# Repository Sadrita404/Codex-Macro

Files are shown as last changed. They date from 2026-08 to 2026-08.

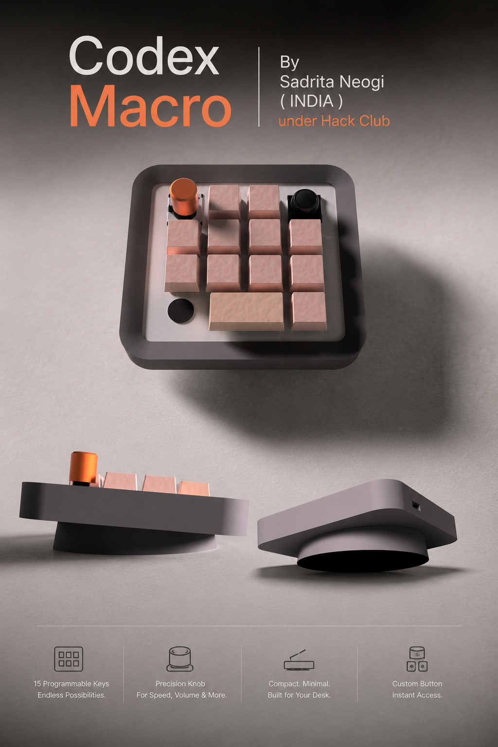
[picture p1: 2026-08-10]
Poster/2Poster.png

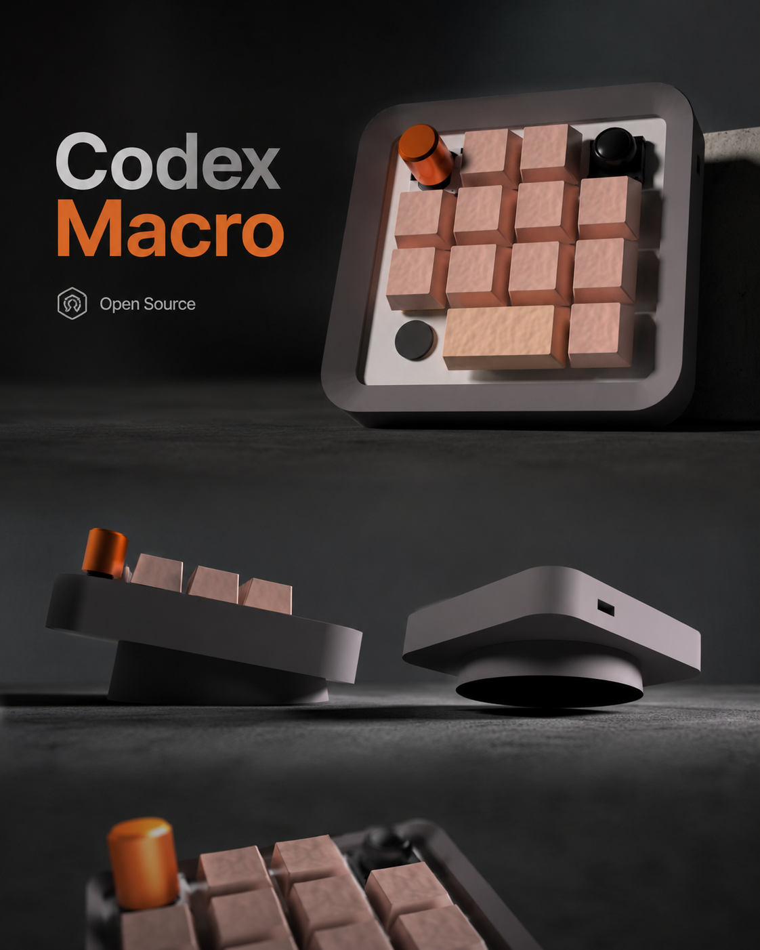
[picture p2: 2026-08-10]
Poster/1Poster.png

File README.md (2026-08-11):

<div align="center">
  <table border="0" cellpadding="0" cellspacing="0">
    <tr>
      <td align="center" style="background: #ffffff; border: 1px solid #d0d7de; border-radius: 12px; padding: 16px; box-shadow: 0 4px 12px rgba(0,0,0,0.05);">
        Rough Layout For The PCB
        <div style="margin-top: 12px; font-family: -apple-system, BlinkMacSystemFont, 'Segoe UI', Helvetica, Arial, sans-serif; font-size: 13px; color: #57606a; font-weight: 500;">
      </td>
    </tr>
  </table>
</div>

|Title | Codex Macro |
|:-- |:--|
|Author | Sadrita Neogi|

## Overview
This is a fully open source Codex Macro , which is basically the clone of Codex Micro which is made by Open AI.

## Why I chose this project?
Actually, behind choosing this project when I saw the post of open AI that they are introducing and codex micro for their codex app then it kind of strike me that I can also make something like that. This is basically an micro pad, but with special feature such as like audio input custom keys with Rotary encoder and joystick.
##  How to use this project

So for using this project, we can do it directly connected to our desktop or laptop. Then we can use it as an Micropath as well as it will also works with the codex app to toggle the different features of the app.

## Features 
* Programmable Mechanical Switches
* Rotary Encoders (Knobs)
* Multi-Directional Joysticks & Switches
* Integrated Microcontrolle (Waveshare RP2040-Zero)
* Microphones (for voice commands)

<div align="center">
  
## Schematic

Screenshot 2026-08-11 at 6 11 34 AM

<div align="center">
  <h2> PCB </h2>
<table width="100%">
  <tr>
    <td width="50%" align="center">
      
    </td>
    <td width="50%" align="center">
      
    </td>
  </tr>
</table>

  <table border="0" cellpadding="10" cellspacing="0" style="border-collapse: collapse;">
    <tr>
      <!-- FRONT SIDE CARD -->
      <td align="center" valign="top" width="50%" style="background: #ffffff; border: 1px solid #d0d7de; border-radius: 12px; padding: 16px; box-shadow: 0 4px 12px rgba(0,0,0,0.05);">
        Front Side View
        <div style="margin-top: 12px; font-family: -apple-system, BlinkMacSystemFont, 'Segoe UI', Helvetica, Arial, sans-serif; font-size: 13px; color: #57606a; font-weight: 600; text-transform: uppercase; letter-spacing: 0.5px;">
          ▲ Front Side View
        </div>
      </td>
      <!-- SPACER FOR GITHUB MOBILE DEGRADATION -->
      <td width="2%">&nbsp;</td>
      <!-- BACK SIDE CARD -->
      <td align="center" valign="top" width="50%" style="background: #ffffff; border: 1px solid #d0d7de; border-radius: 12px; padding: 16px; box-shadow: 0 4px 12px rgba(0,0,0,0.05);">
        Back Side View
        <div style="margin-top: 12px; font-family: -apple-system, BlinkMacSystemFont, 'Segoe UI', Helvetica, Arial, sans-serif; font-size: 13px; color: #57606a; font-weight: 600; text-transform: uppercase; letter-spacing: 0.5px;">
          ▲ Back Side View
        </div>
      </td>
    </tr>
  </table>
</div>
</div>

<h2> Fusion Renders</h2>
<table width="100%">
  <tr>
    <td width="50%" align="center">
      Render 1
    </td>
    <td width="50%" align="center">
      Render 2
    </td>
  </tr>
  <tr>
    <td width="50%" align="center">
      Render 4
    </td>
    <td width="50%" align="center">
      Render 6
    </td>
  </tr>
</table>

<div align="center">
  <h2> Bill of Materials</h2>
</div>

| Component Name | Purpose | Qty | Total Price | Source Link | Distributor |
| :--- | :--- | :---: | :---: | :---: | :---: |
| **PCB(moq5)** | The Main Board | 5 | $4.00 | [JLC PCB](https://jlcpcb.com/) | JLC PCB |
| **Waveshare RP2040-Zero** | The Controller Board | 1 | $4.50 | [Robu](https://robu.in/product/waveshare-rp2040-zero-without-header/) | Robu |
| **SMD LED** | For the board | 20 | $0.20 | [Robu](https://robu.in/product/xl-1608ubc-04-xinglight-20ma-240mcd-colorless-transparent-lens-20%e2%84%8385%e2%84%83-positive-stick-455nm475nm-blue-120-70mw-3-3v-0603-led-i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) | Robu |
| **Microphone Module** | For the audio input | 1 | $1.60 | [Robu](https://robu.in/product/inmp441-mems-high-precision-omnidirectional-microphone-module-i2s/) | Robu |
| **Joystick Switches** | For the Control | 1 | $0.35 | [Robu](https://robu.in/product/10109-6p-wx-shou-han-smd-6p10x10mm-multi-directional-switches-rohs/) | Robu |
| **47 Ohm 0.25W Metal Film Resistor** | For the led | 40 | $0.12 | [Robu](https://robu.in/product/47-ohm-0-25w-metal-film-resistor-pack-of-100/) | Robu |
| **Rotary Encoder** | For the Control | 1 | $0.40 | [Robu](https://robu.in/product/hongyan-rs11-threadless-insert/) | Robu |
| **1N4148 1W Zener Diode** | For the keys | 20 | $0.30 | [Robu](https://robu.in/product/1n4148-1w-zener-diode-pack-of-50/) | Robu |
| **Keycaps(set)** | For the keys | 1 | $7.50 | [Neomacro](https://neomacro.in/products/mahjong-mx-style-keycaps?variant=50665429369110) | Neomacro |
| **Low Profile Switches** | For the Board | 1 | $13.00 | [Neomacro](https://neomacro.in/products/kailh-choc-v2-low-profile-switches?variant=51316563312918) | Neomacro |
| **PLA Filament** | For 3d Print ( I have 3d Printer) | 1 | $6.00 | [Numakers](https://india.numakers.com/products/pla?variant=45708299305129) | Numakers |
| **Shipping** | incl. PCB | - | $16.00 | - | - |
| **Tax** | - | - | $2.20 | - | - |
| **Total (Rounded Off)** | - | - | **$60.00** | - | - |

</div>

## Copyright and License
Copyright (c) 2026 Sadrita Neogi. All rights reserved.

All files are licensed under the MIT license. For more information, see the [LICENSE](LICENSE).

Project Under Hack Club

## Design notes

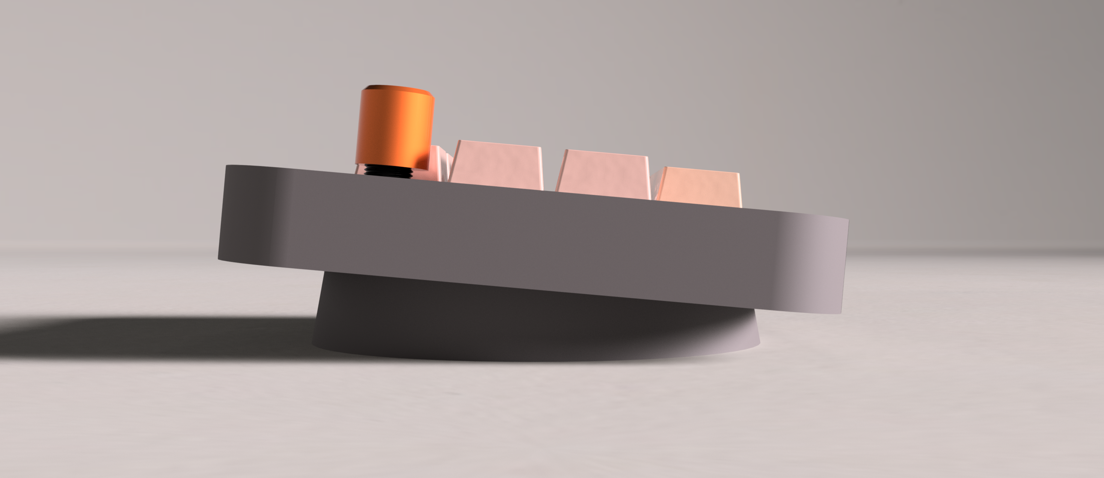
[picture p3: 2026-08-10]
Renders/Render 2.png

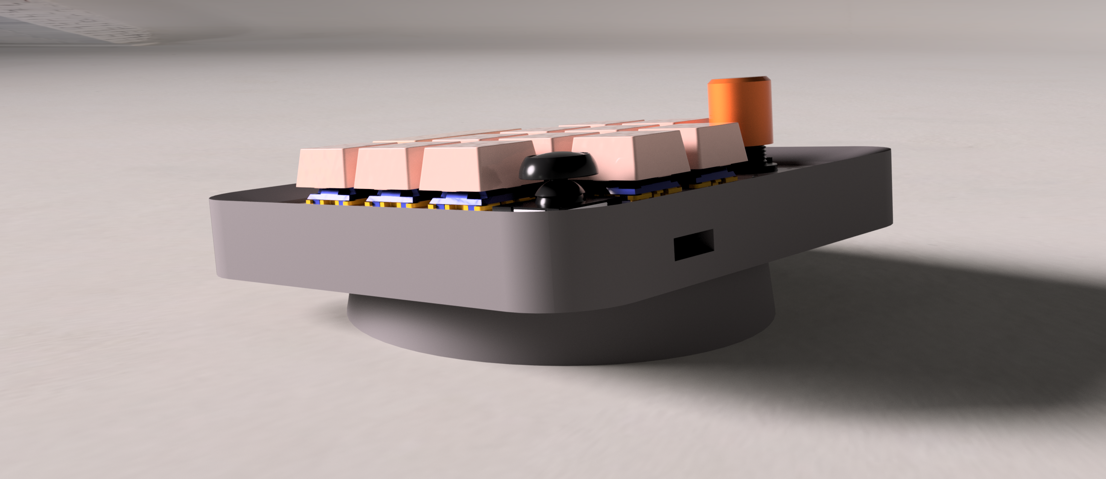
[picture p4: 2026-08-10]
Renders/Render 5.png

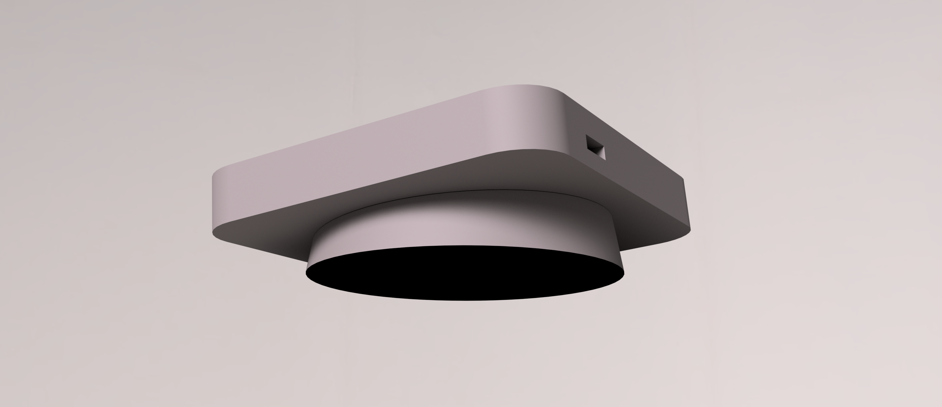
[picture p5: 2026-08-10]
Renders/Render 4.png

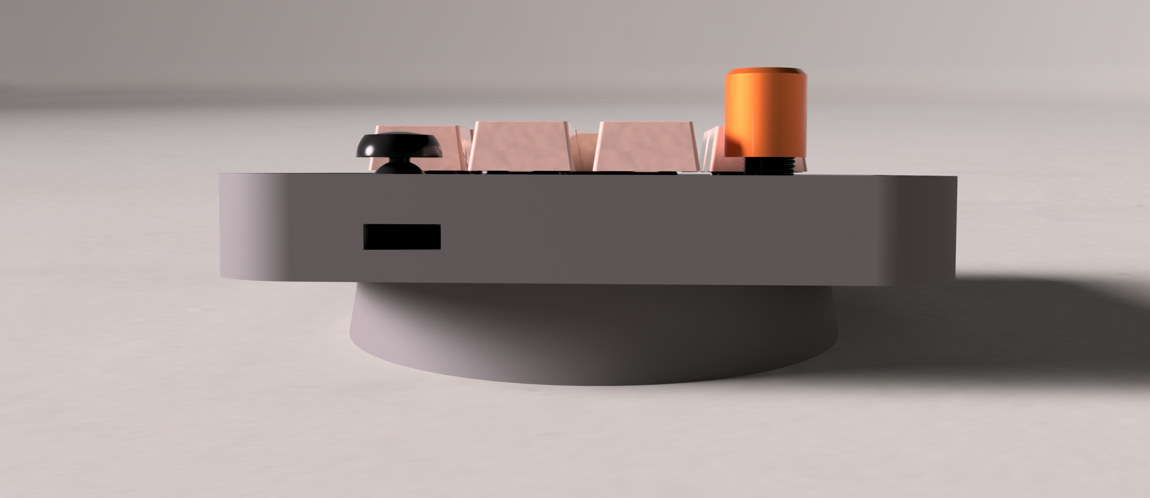
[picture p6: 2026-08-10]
Renders/Render 6.png

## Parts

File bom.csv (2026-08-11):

Name | Purpose | Quantity | Price in USD | Link | Distributor
PCB(moq5) | The Main Board | 5 | 4 | https://jlcpcb.com/ | JLC PCB
Waveshare RP2040-Zero | The Controller Board | 1 | 4.5 | https://robu.in/product/waveshare-rp2040-zero-without-header/ | Robu
SMD LED | For the board | 20 | 0.2 | https://robu.in/product/xl-1608ubc-04-xinglight-20ma-240mcd-colorless-transparent-lens-20%e2%84%8385%e2%84%83-positive-stick-455nm475nm-blue-120-70mw-3-3v-060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 | Robu
Microphone Module | For the audio input | 1 | 1.6 | https://robu.in/product/inmp441-mems-high-precision-omnidirectional-microphone-module-i2s/ | Robu
Joystick Switches | For the Control | 1 | 0.35 | https://robu.in/product/10109-6p-wx-shou-han-smd-6p10x10mm-multi-directional-switches-rohs/ | Robu
47 Ohm 0.25W Metal Film Resistor | For the led | 40 | 0.12 | https://robu.in/product/47-ohm-0-25w-metal-film-resistor-pack-of-100/ | Robu
Rotary Encoder | For the Control | 1 | 0.4 | https://robu.in/product/hongyan-rs11-threadless-insert/ | Robu
1N4148 1W Zener Diode | For the keys | 20 | 0.3 | https://robu.in/product/1n4148-1w-zener-diode-pack-of-50/ | Robu
Keycaps(set) | For the keys | 1 | 7.5 | https://neomacro.in/products/mahjong-mx-style-keycaps?variant=50665429369110 | Neomacro
Low Profile Switches | For the Board | 1 | 13 | https://neomacro.in/products/kailh-choc-v2-low-profile-switches?variant=51316563312918 | Neomacro
PLA Filament | For 3d Print ( I have 3d Printer) | 1 | 6 | https://india.numakers.com/products/pla?variant=45708299305129 | Numakers
Shipping | incl. PCB |  | 16
Tax |  |  | 2.2
Total round off |  |  | 60

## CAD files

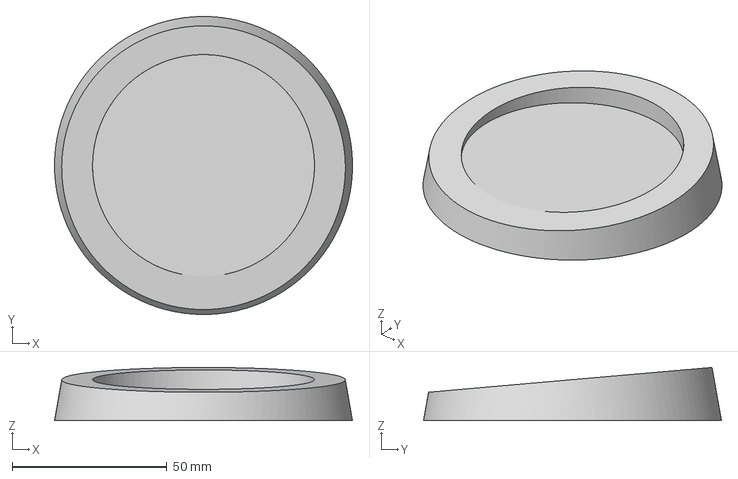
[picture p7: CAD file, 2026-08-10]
3d Print/Bottom Lid.3mf
96.2 x 96.2 x 17.1 mm

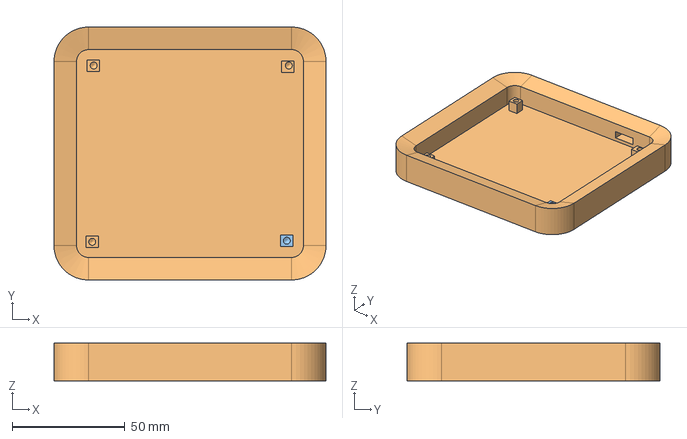
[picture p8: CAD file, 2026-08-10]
CAD/Codex Macro Case.step
120.5 x 112.0 x 16.7 mm

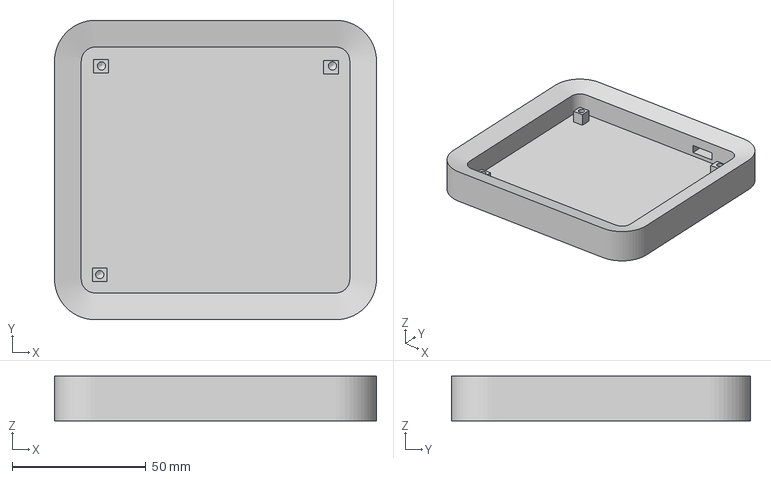
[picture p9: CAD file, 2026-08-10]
3d Print/Base Case.3mf
120.5 x 112.0 x 16.7 mm

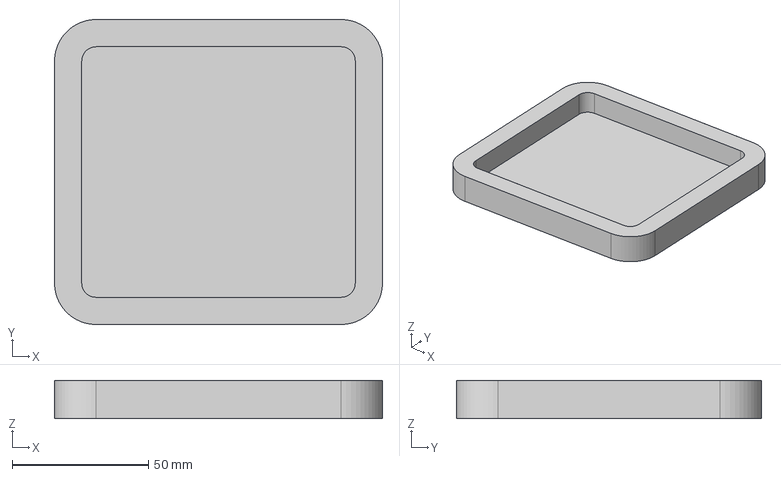
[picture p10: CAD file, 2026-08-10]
CAD/Codex Macro lid.step
120.5 x 112.0 x 14.0 mm

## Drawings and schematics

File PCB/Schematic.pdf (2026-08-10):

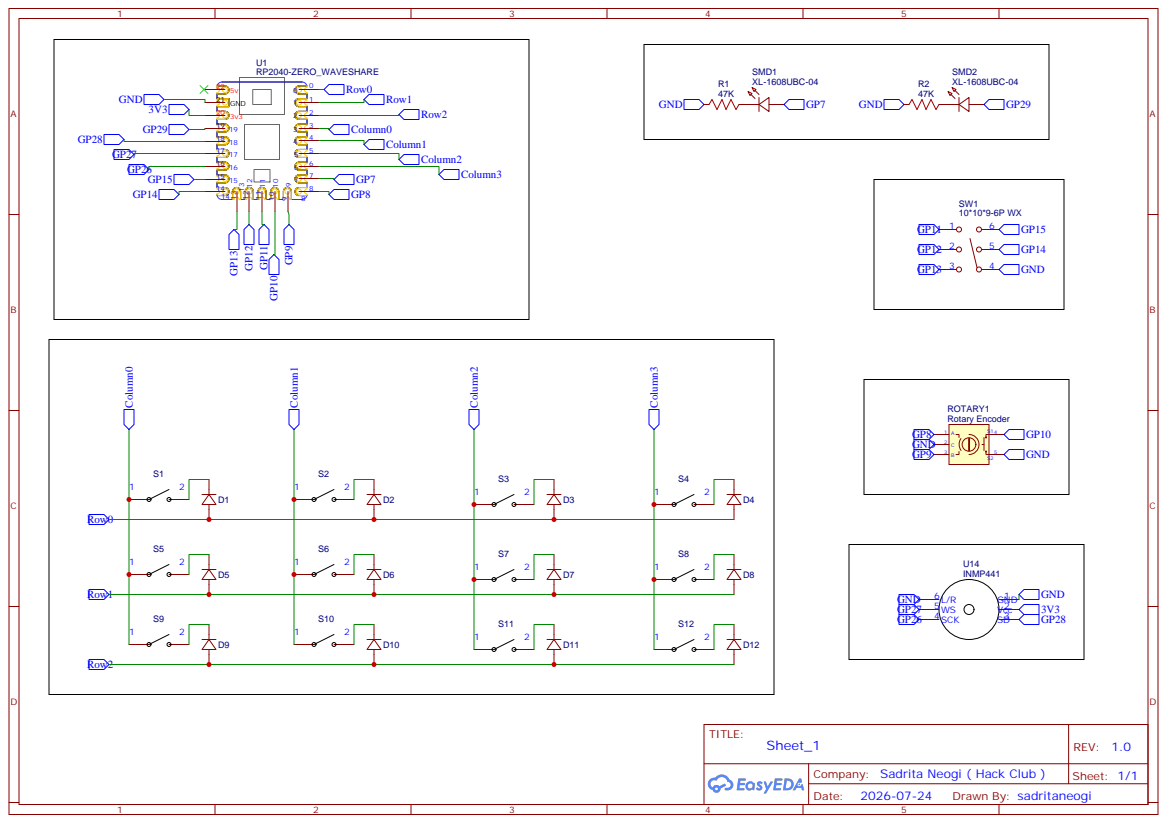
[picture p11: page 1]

Company: Sadrita Neogi ( Hack Club )

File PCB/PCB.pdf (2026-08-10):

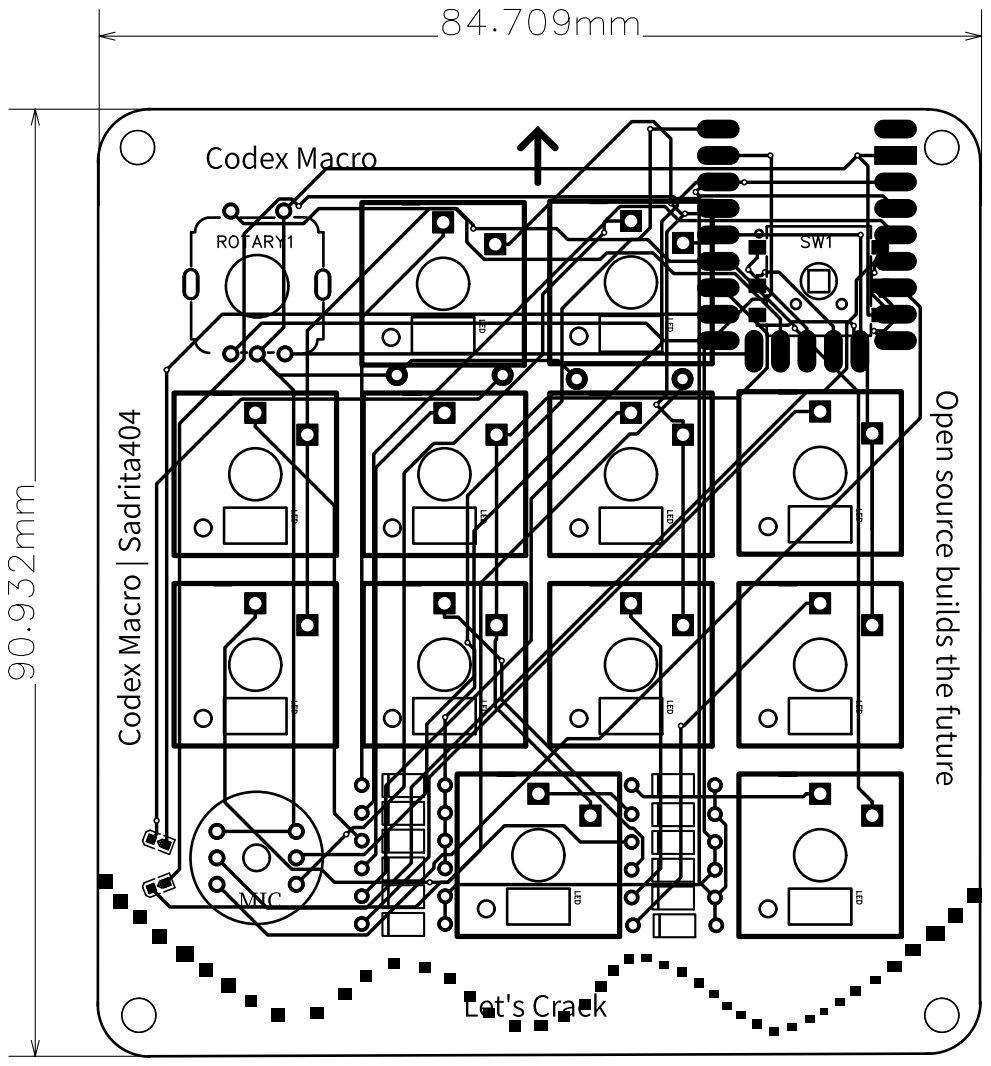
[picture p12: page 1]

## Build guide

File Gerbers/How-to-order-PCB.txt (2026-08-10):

How to Order PCB

Please refer to:
https://docs.easyeda.com/en/PCB/Order-PCB

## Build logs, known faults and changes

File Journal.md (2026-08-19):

| Title | Codex Macro|
| :-- | :---|
|Author |Sadrita Neogi|
|Type | Hardware  |
Total Hrs |  19.2 |

## Started design designing the product and taking info from the previous one that had already existed.

So for this project the main design inspo for me was the all new Codex Micro by Open Ai ( made by the company Work Louderand I like the brand ) So I thought to make a same thing under budget as the Codex Micro is costed at $230which is too much for what it's offer so I named it " Codex Macro "

#### Inspo 



#### Mine Design 

design

This is just the wire frame of the project and I have made it just for the reference so that I can use it to design the PCb also the CAD model of that

_Total Time = 15 min_

---

## Now I started research about the components that I can use for this project that can be cost-effective as well as easy to use, and I can get all the data sheet of that so that I can make the PCB

For the main Control Board I choose the **Waveshare RP2040-Zero** as this is not too much expensive and I can use it to control most of the components and this will done the job done.
Now I need to see the data sheet of this Waveshare RP2040-Zero to make sure that it will work with all the components.

#### And I am using this datasheet for this which is uploaded in the roubbu.in website - [Link DOC](https://robu-prod-media.s3.ap-south-1.amazonaws.com/products/attachments/8VoZujeD3ppn3I6F0tEKGp6TgBw9RXaVQka7HNXm.pdf)

Screenshot 2026-08-11 at 3 00 20 AM
Screenshot 2026-08-11 at 3 00 34 AM

### The AHB-Lite Crossbar are perfect for the work that I will do with it 

Screenshot 2026-08-11 at 3 00 53 AM

The Power can be a problem but I will use type-c connected to it and will work good with wired connection 

Screenshot 2026-08-11 at 3 01 57 AM

### the Pin out 



_Total Time = 1.1hrs_

---

## Now for the switches I want it to be a low profile as I saw in the "Codex Micro"

So after a going to websites I have found many low profile switches but I could not find the datasheet of that and without the datasheet I can't design the PCB . So for that reason I am going with the Kailh Choc v2 Low Profile Switches as they have detailed datasheet for the PCB footprint .

Screenshot 2026-08-11 at 3 23 00 AM

### Kailh Choc v2 Low Profile Switches - [Datasheet DOC](https://cdn.shopify.com/s/files/1/0657/6075/5954/files/SPEC-CPG135301D03_Kailh_Choc_V2_Low_Profile_Blue_Switch.pdf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)

Screenshot 2026-08-11 at 3 13 55 AM

Screenshot 2026-08-11 at 3 14 07 AM

Screenshot 2026-08-11 at 3 14 28 AM

Screenshot 2026-08-11 at 3 14 43 AM

Screenshot 2026-08-11 at 3 15 27 AM

So from the datasheet I write all the important details about the switches that I need to make the pcb like the clearence , distance ,etc

### Footprint in EasyEDA for  Kailh Choc v2 Low Profile Switches

Screenshot 2026-08-11 at 3 41 57 AM

_Total Time = 1.3hrs_

---

## Now the rotary encoder switch and the joystick switch 5 way

For this I found some of the options but most of them are not available in India so I need to search for more components and then I found out all the options in the robu also I got the right footprint for all the components and I match the foot prints in the EasyEDA website and they were all correct and good to go with the PCb and the Waveshare RP2040-Zero the main board 

Screenshot 2026-08-11 at 3 37 31 AM

### Datasheet - [Link Doc](https://robu-prod-media.s3.ap-south-1.amazonaws.com/products/attachments/euNhwNi9MOSVJ2z0tQazayT965JqkDky92OkwhHG.pdf)

Screenshot 2026-08-11 at 3 38 15 AM

Screenshot 2026-08-11 at 3 36 27 AM

Now the Multi-Directional Switches for this I have choose this

Screenshot 2026-08-11 at 3 39 21 AM

### Datasheet - [Link Doc](https://robu-prod-media.s3.ap-south-1.amazonaws.com/uploads/2025/08/C2858290.pdf)

Screenshot 2026-08-11 at 3 39 54 AM

Screenshot 2026-08-11 at 3 40 35 AM

Screenshot 2026-08-11 at 3 40 51 AM

_Total Time = 2.2hrs_

---

## Now the Microphone and the small leds

For this I will use the XL-1608UBC leds and for the microphone I will go for the INMP441 MEMS High Precision Omnidirectional Microphone Module I2S as this is budget friendly also meets the requirements that I needed to make this project so that I can use it for the voice commands through the micro pad, and it will directly showcase in the desktop

Screenshot 2026-08-11 at 3 55 51 AM

### Datasheet - [Link Doc](https://robu-prod-media.s3.ap-south-1.amazonaws.com/products/attachments/9MGXhjupqmHXpZtpmVg7DCaznTPNYbZJjBvXqi6P.pdf)

Screenshot 2026-08-11 at 3 56 03 AM

Screenshot 2026-08-11 at 3 56 47 AM

### PCB DESIGN AND LAND PATTERN LAYOUT

Screenshot 2026-08-11 at 3 57 11 AM

### Digital Low-Pass Filter Magnitude Response - will work for this project 

Screenshot 2026-08-11 at 3 58 02 AM

### Footprint on EasyEDA

Screenshot 2026-08-11 at 3 58 42 AM

Screenshot 2026-08-11 at 3 59 42 AM

This took me a lot of time to cross verify the project again and again so that it will works fine so that I can make the PCB perfectly with all of this components 

_Total Time = 2hrs_

---

## Now the schematic of the PCB

This look a lot of time for me to correctly choose the components and then the footprint that will match with the datasheet of the components.
So for this I first add all the components to the schematic page and they connecting all the components one by one 

### The Waveshare RP2040-Zero

Screenshot 2026-08-11 at 4 05 33 AM

### The Smd leds

Screenshot 2026-08-11 at 4 06 17 AM

### The Micro phone 

Screenshot 2026-08-11 at 4 06 58 AM

### The rotary encoder switch

Screenshot 2026-08-11 at 4 07 10 AM

### The joystick switch

Screenshot 2026-08-11 at 4 07 37 AM

### all 12 switches with 12 1N4148 1W Zener Diode 

Screenshot 2026-08-11 at 4 08 17 AM

Screenshot 2026-08-11 at 4 09 41 AM

**Now I need to make some changes to the schematic and after that it will be good to go**

**all are correct the U_22 had no connection so it will be blank**

Screenshot 2026-08-11 at 4 11 21 AM

## Final schematic 

Screenshot 2026-08-11 at 4 10 45 AM

_Total Time = 4hrs_

---

## Now the PCB

After completing designing the full schematic for the project. Now I convert the schematic into PCV, where I need to place all the components to their designated spot, and then I need to trace all the places and after that, I need to run the DRC check and then if everything is fine, then I can complete generating the Garber file for the project.

Screenshot 2026-08-11 at 4 14 12 AM

Screenshot 2026-08-11 at 4 15 10 AM

Screenshot 2026-08-11 at 4 16 18 AM

Screenshot 2026-08-11 at 4 17 34 AM

Screenshot 2026-08-11 at 4 19 47 AM

Screenshot 2026-08-11 at 4 20 02 AM

So after making the PCB components to their designated spot, and I am happy to see the layout that is currently coming out, and I want to replicate the codex micro and it is exactly looking like that now, I need to trace all the pads and for this, I am using 0.31mm of trace width and they should also give us in good connectivity overall.

Screenshot 2026-08-11 at 4 21 24 AM

### This just the start now I need to work on the Main PCB to add all the 3d models to make the traces more wide also make the footprint to be good .

_Total Time = 1.3hrs_

---

## Final PCB Done

After a lot of doing the PCB and making some changes to the schematic, also, I forgot to add the resistor to the small LED after that, I have also placed the components in such a way as that all the switch along with the key caps are now perfectly fit, and I have also placed the microphone LED Rotary encoder all of this in the correct places along with. I have also make that trace line width to more wide for good connectivity and added some good silk screen .

### DRC Check all OKK

Screenshot 2026-08-11 at 7 35 09 AM

Screenshot 2026-08-11 at 4 25 05 AM

Screenshot 2026-08-11 at 4 25 17 AM

### Final look 

Screenshot 2026-08-11 at 4 25 35 AM

Screenshot 2026-08-11 at 4 25 49 AM

_Total Time = 2hrs_

---

## Now the CAD Part for this 

So for the CAD part I will go for fusion360 to make the case of this project and also the final render of it.

For this first I need to take the dimensions of the PCB 

Screenshot 2026-07-25 at 7 00 01 AM

So after making the PCB completed, I take the dimensions of the PCB and import that in the fusion 360 and started designing the case around it and I also left some millimetres off so that the PCB can fit inside it perfectly, like I have given a clearance for the PCB.

Screenshot 2026-07-25 at 7 02 29 AM

Screenshot 2026-07-25 at 7 49 32 AM

Screenshot 2026-07-25 at 7 51 20 AM

Screenshot 2026-07-25 at 7 52 01 AM

**The Base case is complete**

_Total Time = 0.6hrs_

---

## Now I need to make a slop like structure for the case so that it will looks good 

So I started trying different methods like how I will make this kind of design like the slop one
For the next design part, I want the age around the PCB to be slope inwards means towards the PCB and for that, I have tried different method to do it, but I cannot find any good options in the fusion 360 where I can directly make this so I have improvise it with the slope  graph

Screenshot 2026-07-25 at 8 59 54 AM

Screenshot 2026-07-25 at 9 00 16 AM

Screenshot 2026-08-19 at 11 50 10 PM

**After a couple of tries I have finally made the slop like structure for the case now I need to make the base part which I will do later**

This took me a lot of time as there is not dedicated tool in fusion to make this type of design so I had to make it from scratch 

_Total Time = 1.1hrs_

---

## Now adding holes for the type-c and plate for the mounting holes for the threaded inserts

After making the main case, now I want to put the PCB inside the case and for that, I need to hold it with the case using some screws and to put the screw inside the case, I have added some holes so that I can later insert some heat set insert onto it and make it functional so that I can also screw the PCB firmly with the case.

Screenshot 2026-07-25 at 9 19 54 AM

Screenshot 2026-07-25 at 9 31 55 AM

_Total Time = 0.51hrs_

---

## The main base of the case 

For this I want it to be like the inspo " Codex Micro " like the slant height one so I started designing that in the fusion and I have made it properly 

Screenshot 2026-07-25 at 10 57 38 AMz

So as I want to replicate the open AI product, and for that, I need to elevate the macro pad little bit from the surface So as I want to replicate the open AI product, and for that, I need to elevate the micro bed little bit from the surface so to do that, I have made one circular round thing and I have make it on a angle like I have cut it on an angle so that it will tilt from the front side a little bit giving it good looking and also it is economic to use, like we don't need to move our whole palm towards the macropad to use it.

Screenshot 2026-07-25 at 11 03 40 AM

Screenshot 2026-07-25 at 11 04 06 AM

Screenshot 2026-07-25 at 11 12 02 AM

_Total Time = 0.44hrs_

---

## Now the final CAD assembly of the project 

So I started downloading all the 3d models for the switches , keycaps , mic , encoder, etc and added it to the final cad model that I have done in fusion360

I have finally assemble all the components into the final CAD model and export it, and after that, I will publish it to the GitHub. This took me a lot of time to make the alignment correct, but after all of that, the final project turned out to be good. I like it.

Screenshot 2026-08-19 at 11 54 23 PM
Screenshot 2026-08-19 at 11 54 37 PM

Screenshot 2026-07-25 at 5 32 52 PM

I have also added colour to the model so that I can render some good images for it 

_Total Time = 1.3hrs_

---

## Rendering some good images for the gitrepo 

I am rendering the images since this is also helps the other user that how the final project looks like after I built it, so I prefer to render some good images since fusion 360 offers that in his own app, so I render some images so that I can also put it in the GitHub as well as it will work as the showcase of the project

Screenshot 2026-07-25 at 5 33 05 PM

Screenshot 2026-07-25 at 5 33 15 PM

### Final Render 

Render 1

Render 2

Render 4

Render 6

Render 5

Render 3

_Total Time = 1.1hrs_

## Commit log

2026-08-10 Document microphone and LED components in Journal
    Added details about microphone and LED components, including datasheet links and images. Updated sections for PCB design, schematic components, and final schematic.
2026-08-10 3d print
    [Base Case.3mf, Bottom Lid.3mf]
